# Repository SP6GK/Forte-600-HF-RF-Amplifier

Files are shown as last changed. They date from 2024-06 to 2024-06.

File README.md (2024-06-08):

# Forte 600

This is a hardware repository for a 600 W linear RF amplifier working in the 1.8-30 MHz spectrum. I have performed extensive measurements of the output for different configurations of the output transmission line transformers (TLTs). Unfortunately, I don't have the equipment to test this amplifier above 30 MHz, but according to S11 measurements of the output, it should also cover the 6 m band with lower output power.

I recommend using a single 17 Ohm coaxial cable (HF141-17-FEP by Qaxial) for winding the TLTs. However, as shown in my tests, you can use a parallel combination of 50 and 25 Ohm cables, which are easier to find and less expensive. Such an improvised transformer will have worse Power Added Efficiency (PAE) and won't maintain peak power over the maximum wide bandwidth. The ferrite cores used are Fair-Rite 2661102002.

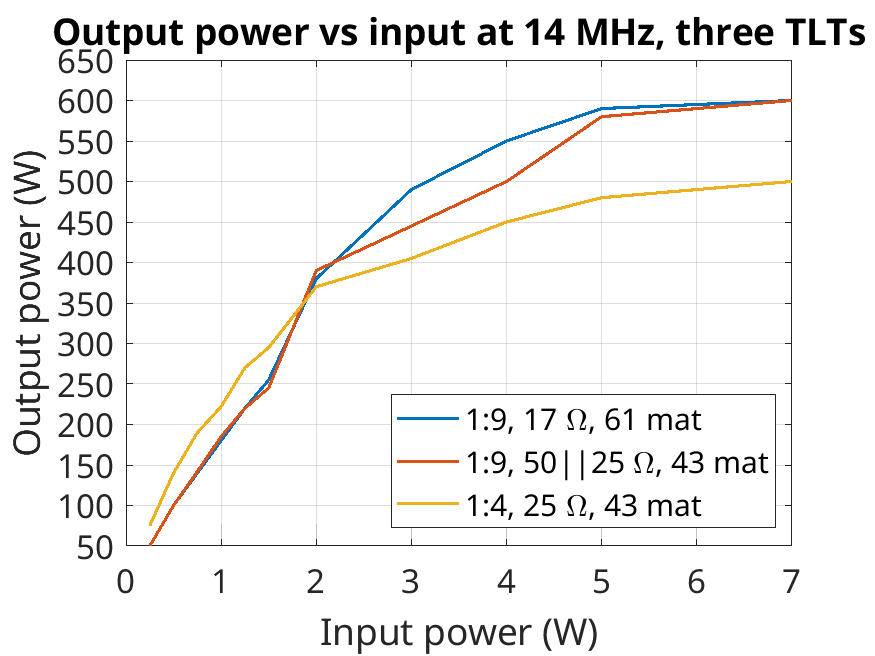
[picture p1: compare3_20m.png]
Output power

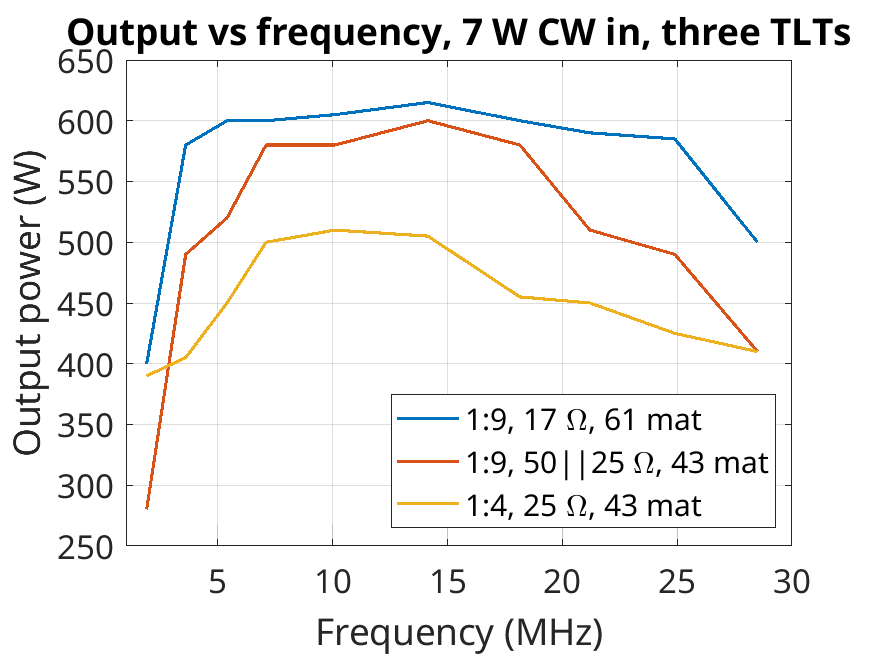
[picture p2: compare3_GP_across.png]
Output power across bands


For more details, you can read my paper or full master thesis, which will be published on my webpage in the coming months: [https://www.sp6gk.com/](https://www.sp6gk.com/).

This project was inspired by Razvan Fatu's 600 W amplifier: [A 600W Broadband HF Amplifier Using Affordable LDMOS Devices](https://qrpblog.com/2019/10/a-600w-broadband-hf-amplifier-using-affordable-ldmos-devices/). The goal of this work was to perform measurements of return loss of the input and output matching network, characterize the linearity, power added efficiency (PAE), and most importantly, the impact of "improvised" TLTs over a "textbook" TLT.

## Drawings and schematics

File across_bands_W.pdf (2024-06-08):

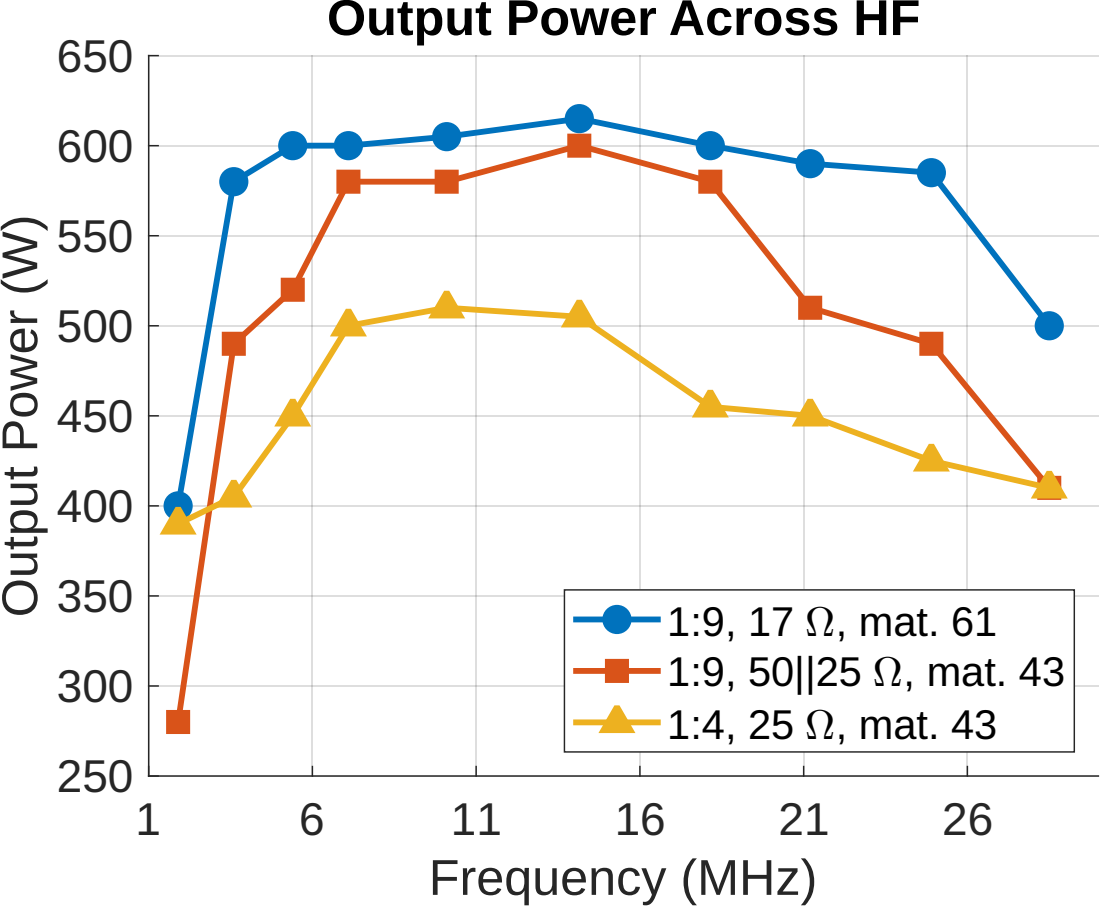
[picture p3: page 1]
Frequency (MHz); utp; 1:9, 17 +, mat. 61 1:9, 50||25 +, mat. 43 1:4, 25 +, mat. 43

Output Power Across HF

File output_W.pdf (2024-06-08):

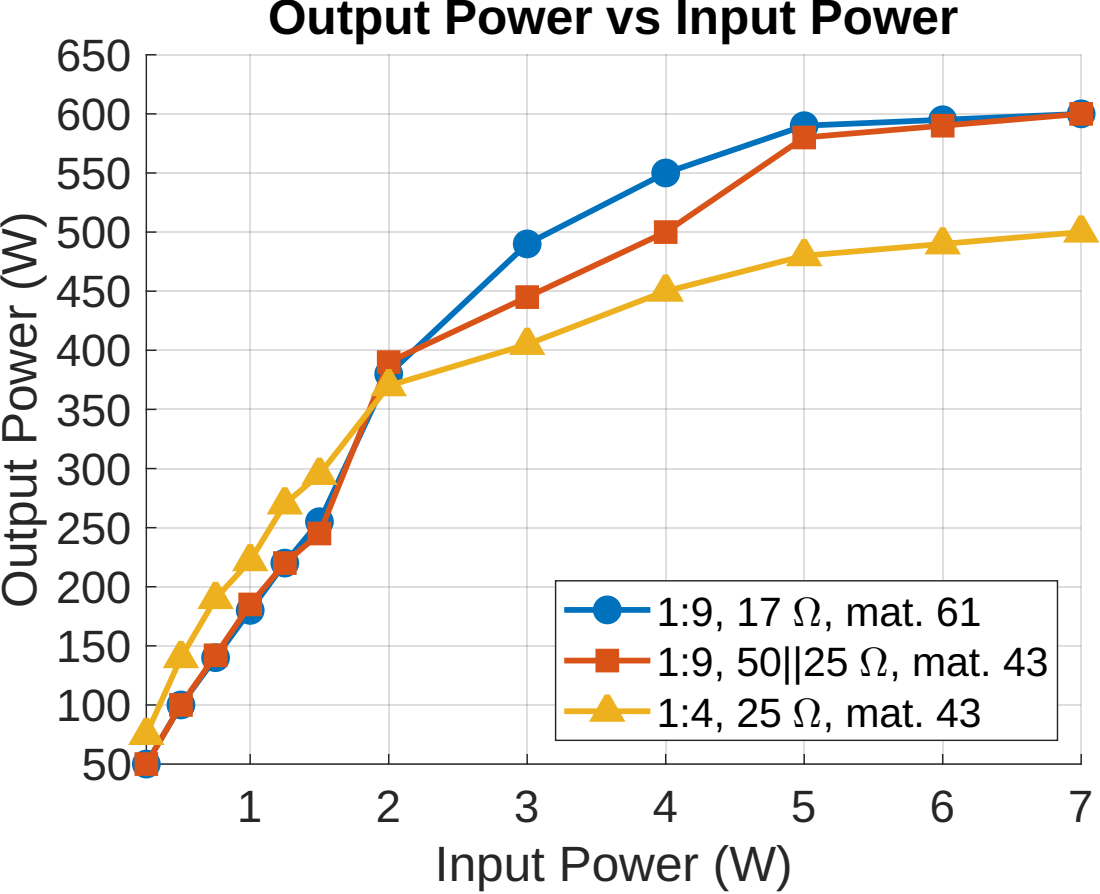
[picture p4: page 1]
7 Input Power (W); Output Power (W)

1:9, 1 | 7 +, m | a t. 6 | 1
1:9, 5 | 0||2 | 5 +, m | a t. 4 3
1:4, 2 | 5 +, m | a t. 4 | 3

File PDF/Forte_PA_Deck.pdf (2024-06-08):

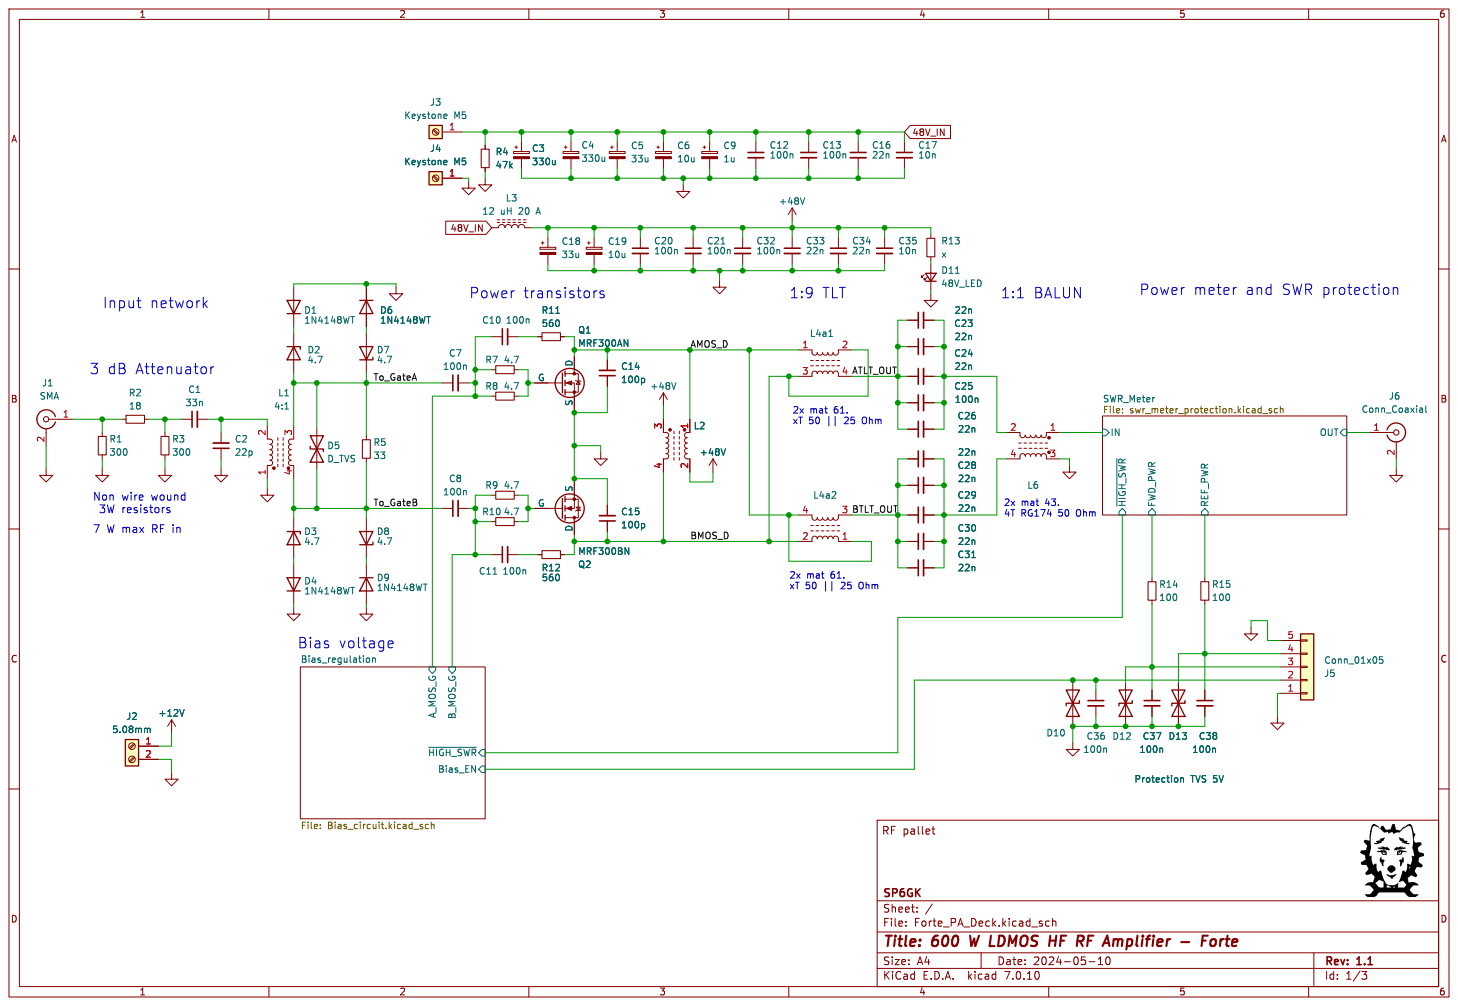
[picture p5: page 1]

Input network Non wire wound

2x mat 43. 4T RG174 50 Ohm 3 dB Attenuator

3W resistors 7 W max RF in

Id: 1/3 Title: 600 W LDMOS HF RF Amplifier - Forte

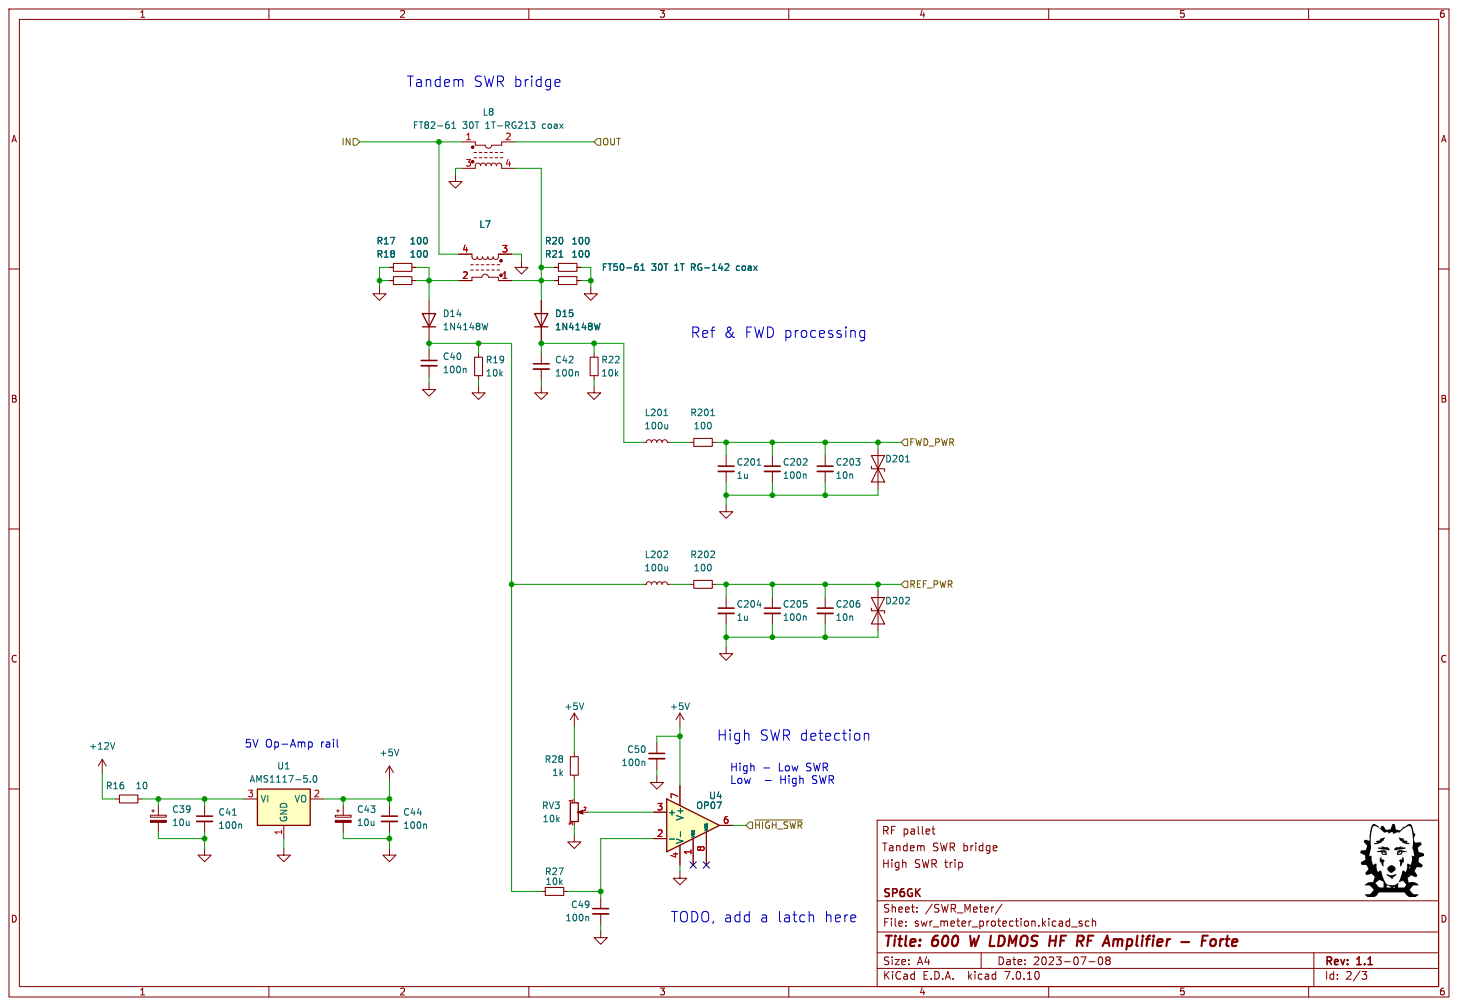
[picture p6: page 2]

Tandem SWR bridge
Low - High SWR Ref & FWD processing

Id: 2/3 Title: 600 W LDMOS HF RF Amplifier - Forte

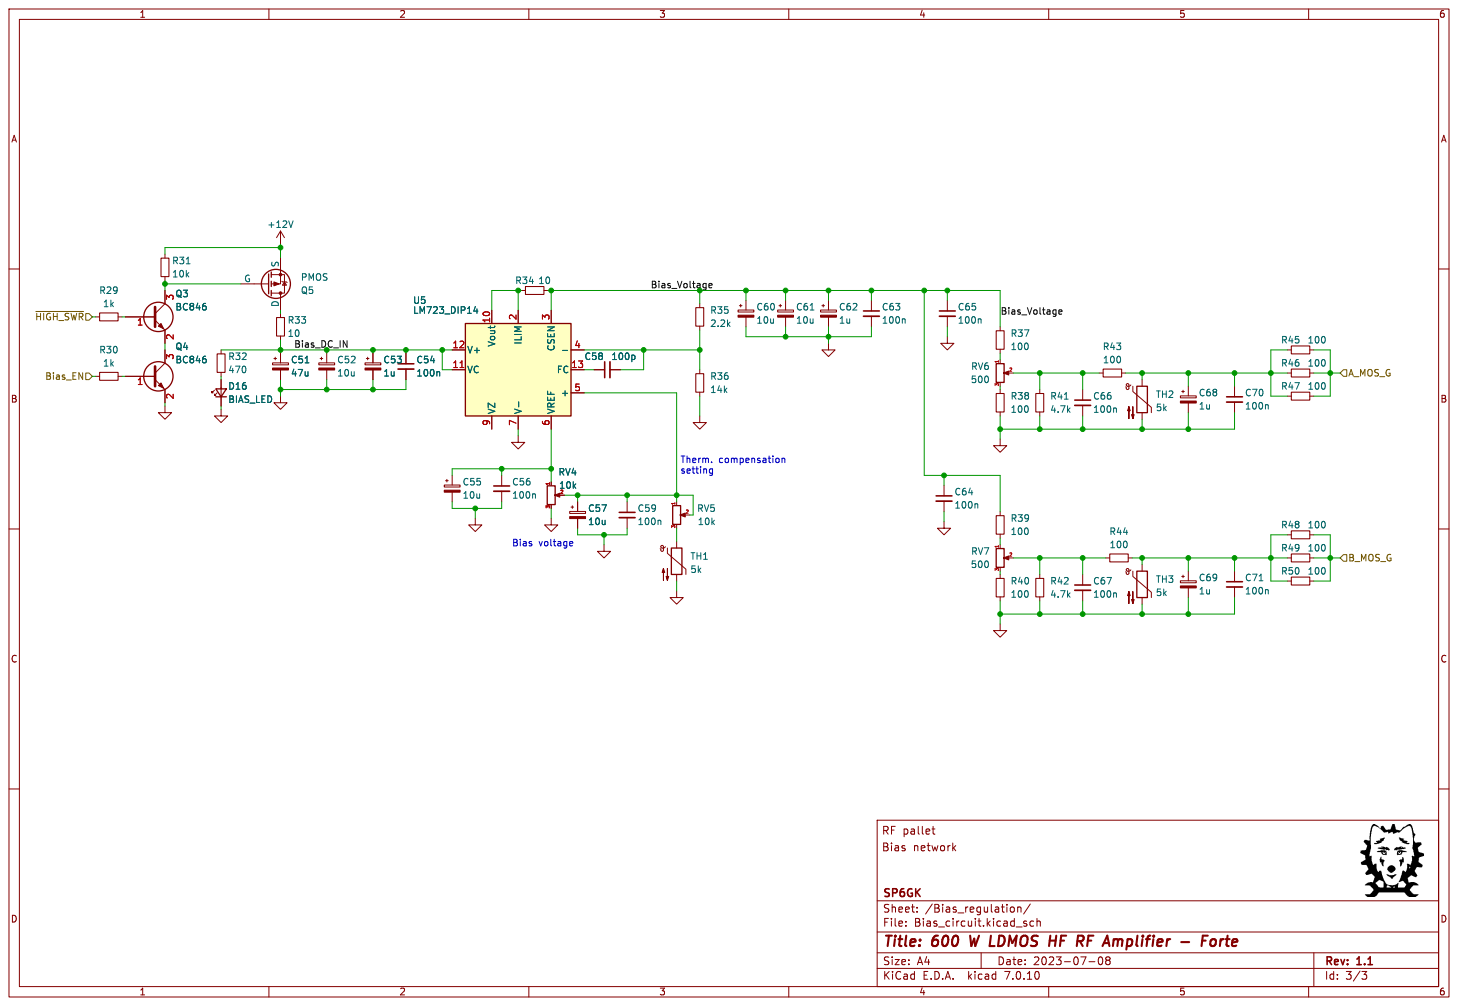
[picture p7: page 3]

Id: 3/3 Title: 600 W LDMOS HF RF Amplifier - Forte

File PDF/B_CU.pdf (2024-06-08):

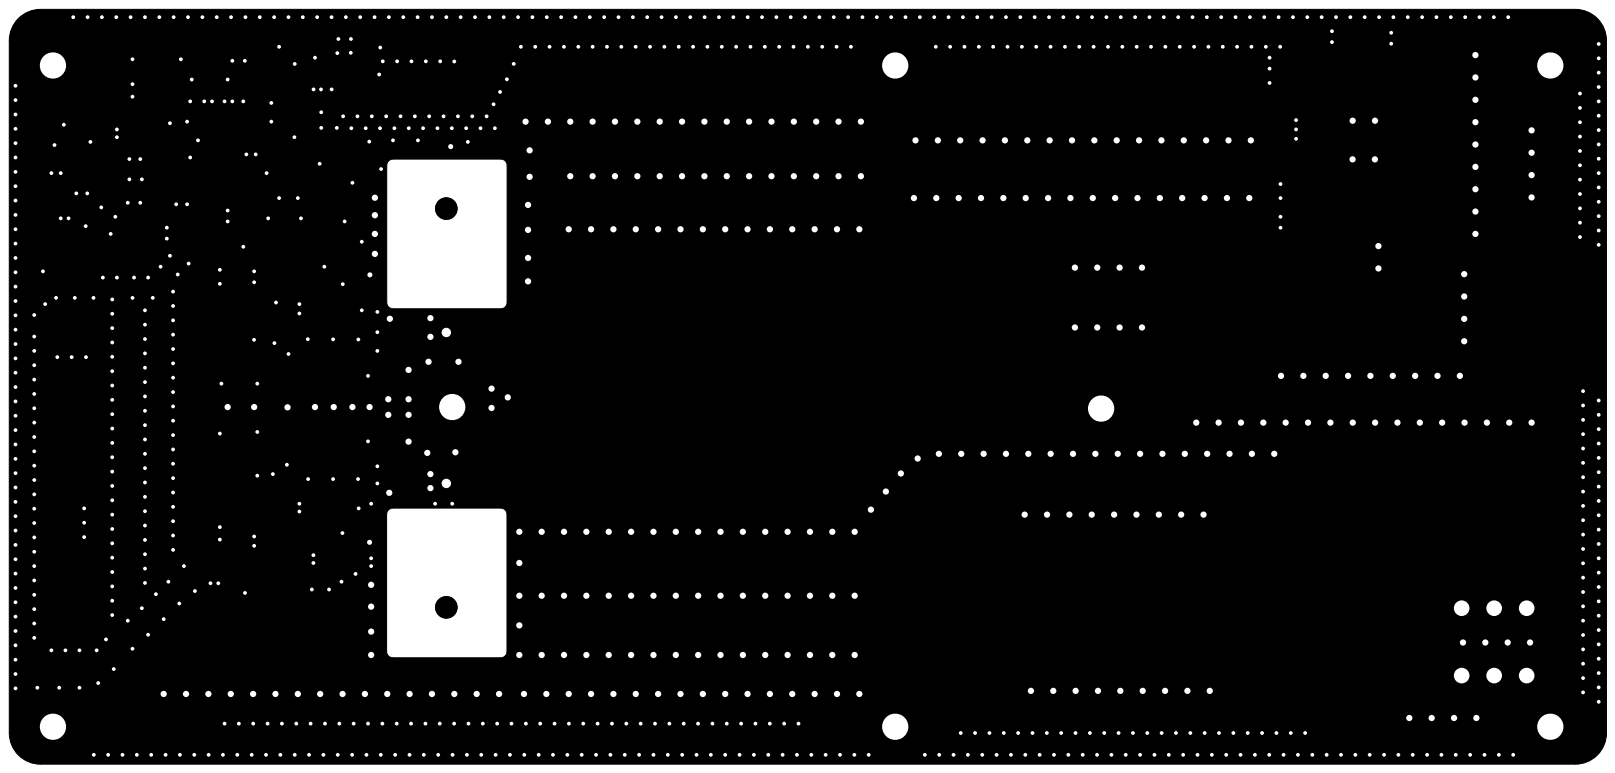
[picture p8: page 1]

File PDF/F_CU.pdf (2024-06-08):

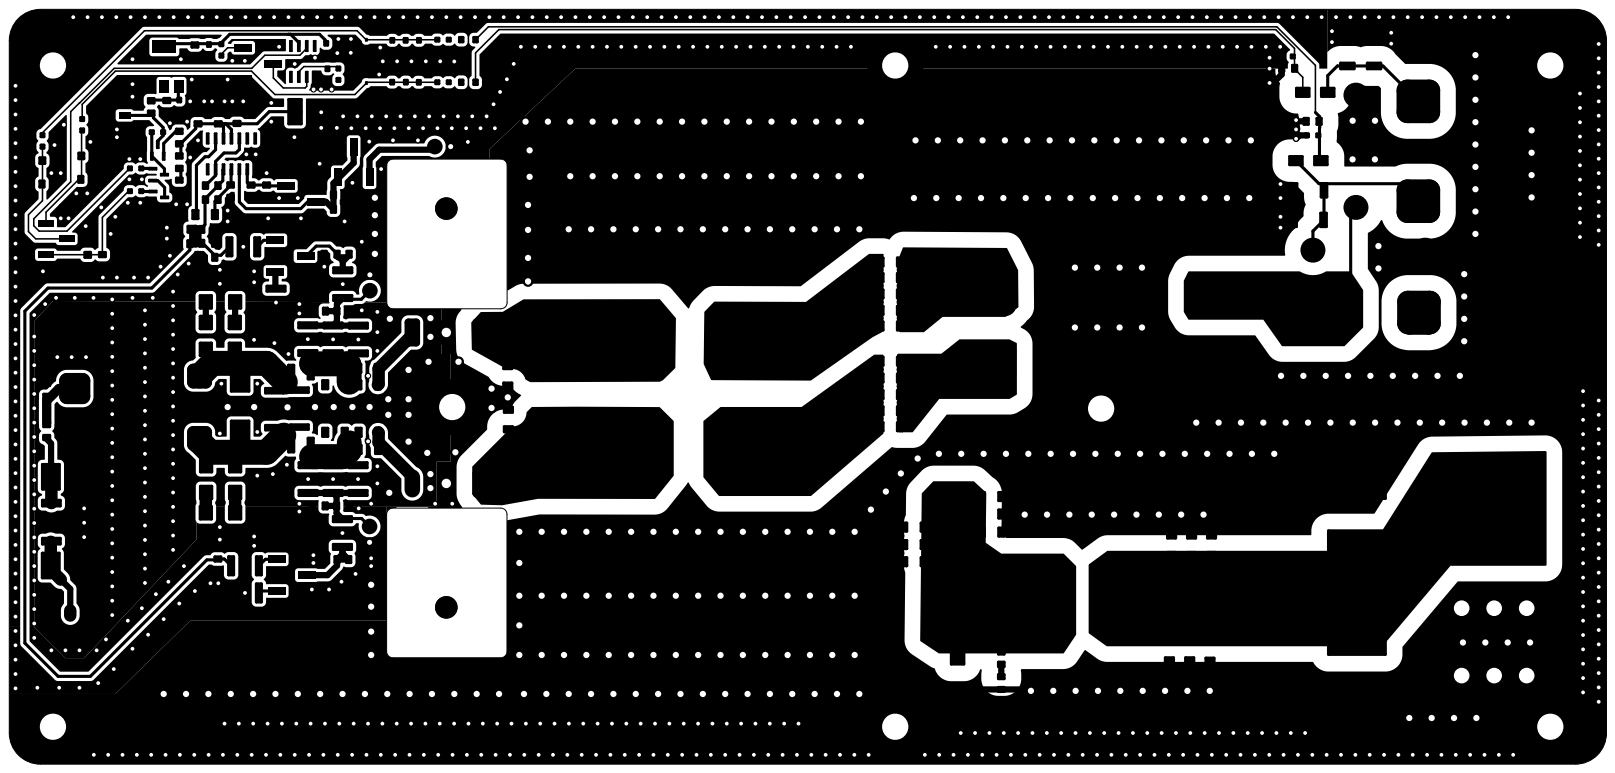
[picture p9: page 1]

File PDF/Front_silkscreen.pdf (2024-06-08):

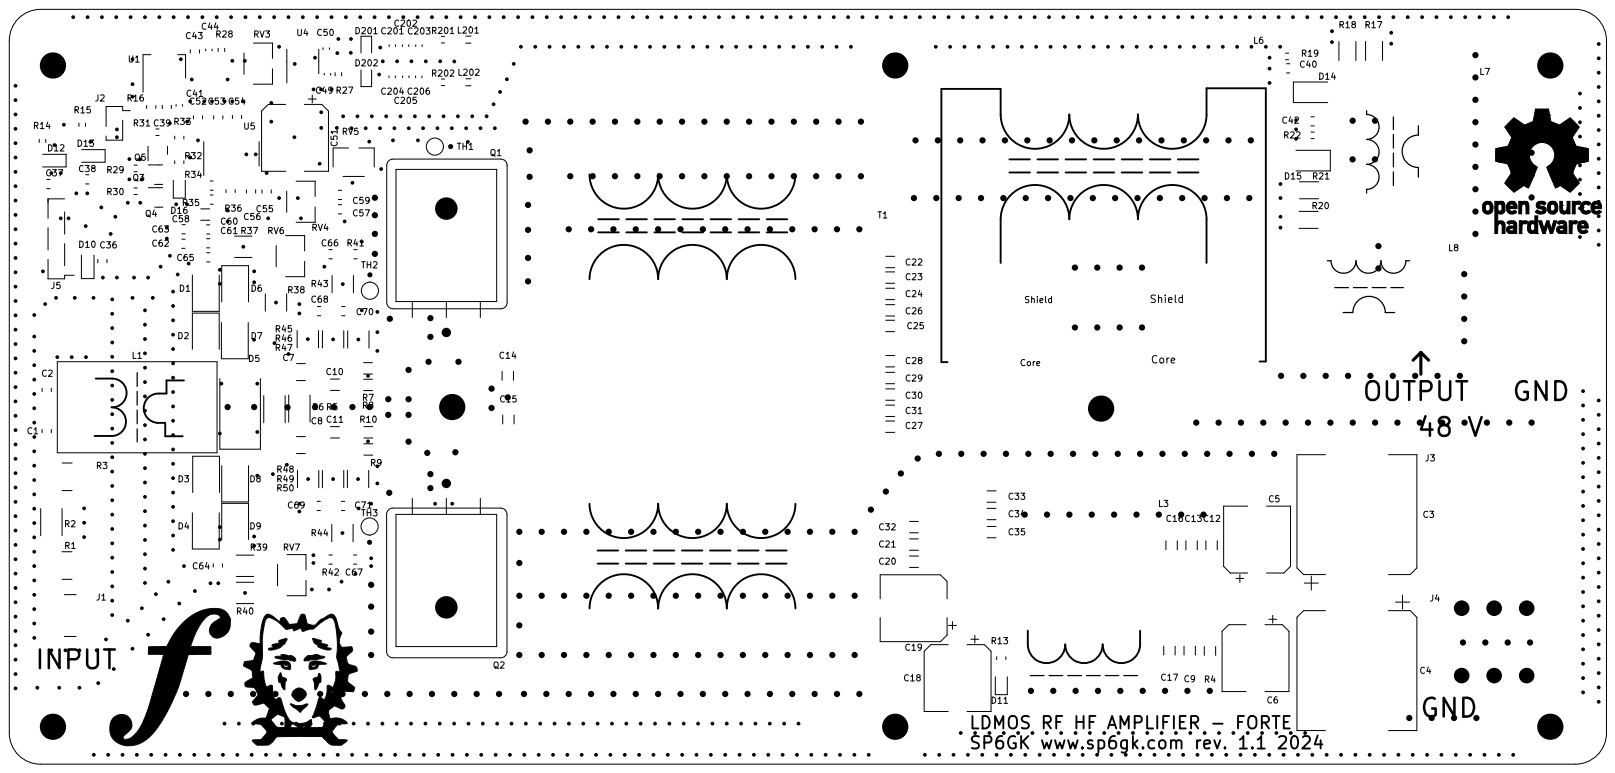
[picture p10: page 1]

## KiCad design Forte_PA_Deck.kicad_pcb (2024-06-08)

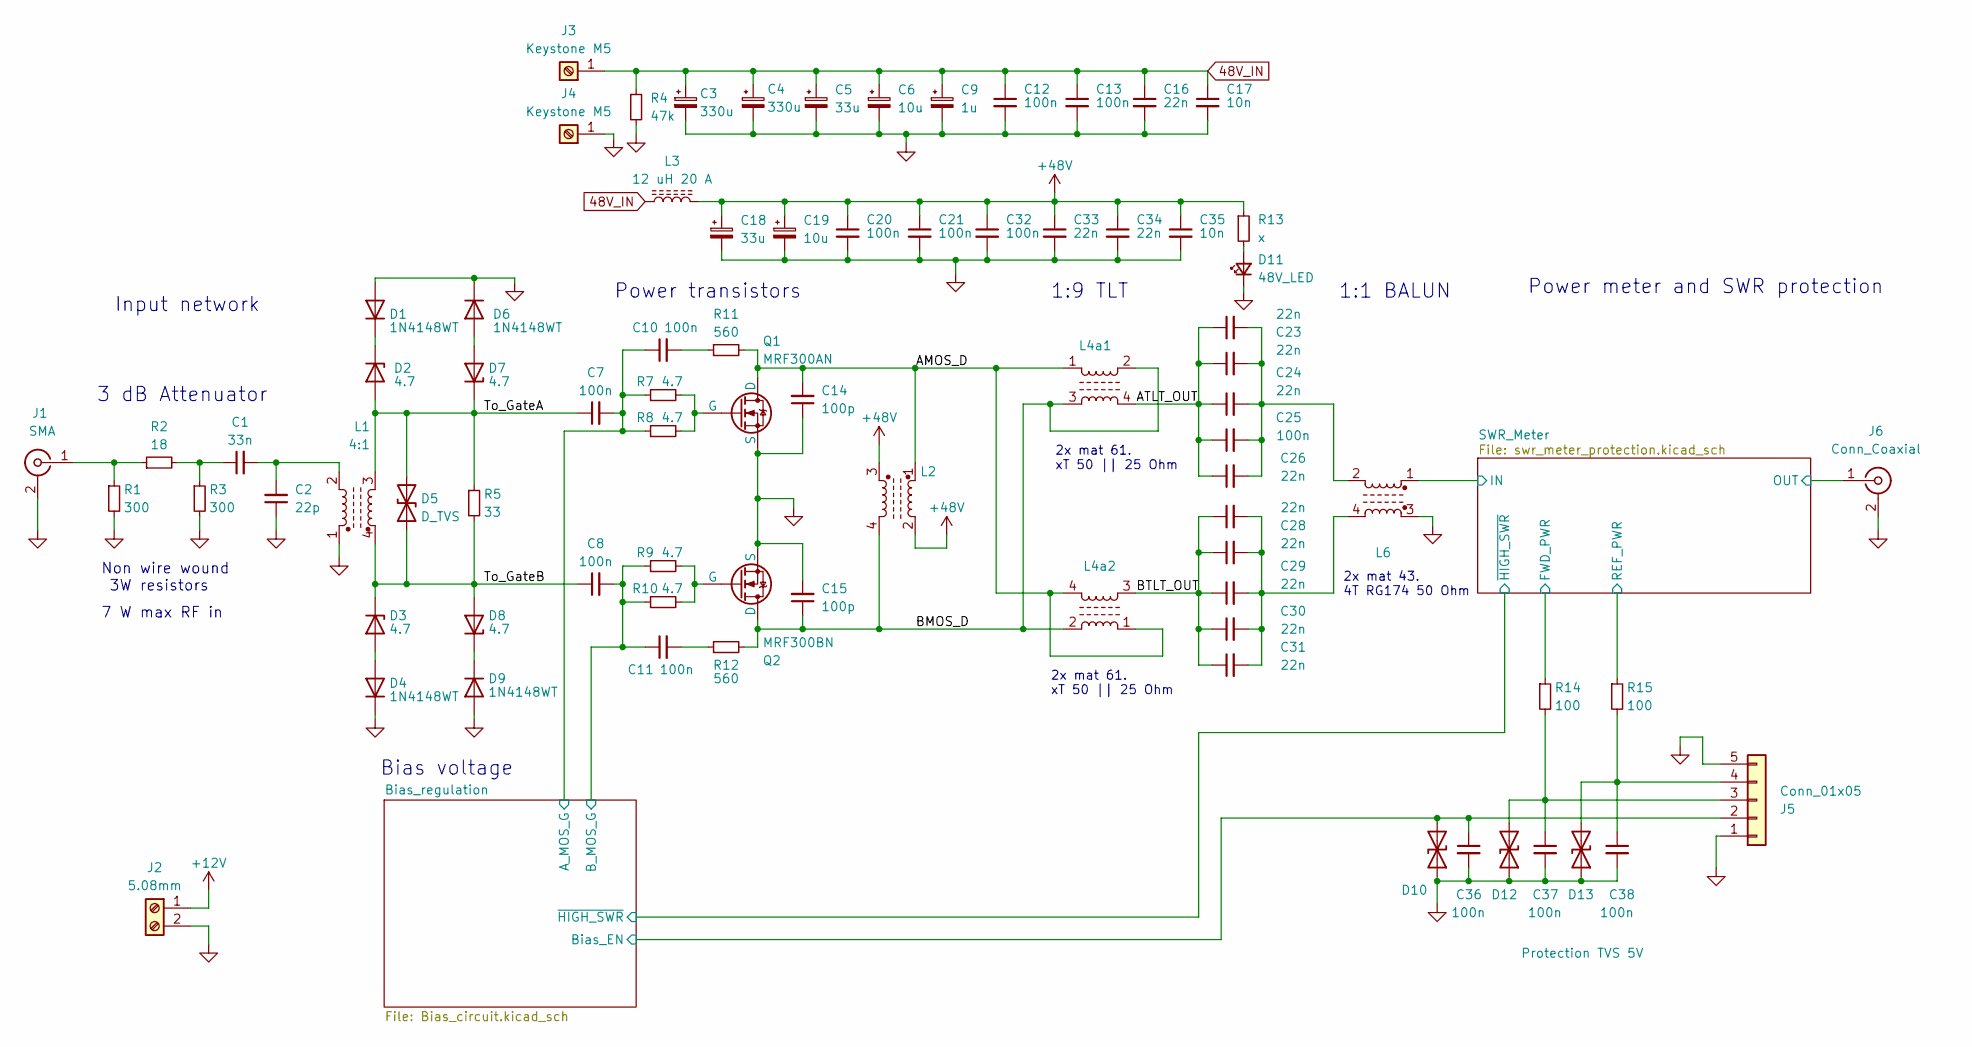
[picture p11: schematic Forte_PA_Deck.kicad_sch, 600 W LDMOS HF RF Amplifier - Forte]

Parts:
C1: 33n; C_0805_2012Metric_Pad1.18x1.45mm_HandSolder
C2: 22p; C_0805_2012Metric_Pad1.18x1.45mm_HandSolder
C3, C4: 330u; CP_Elec_18x17.5
C5, C18: 33u; CP_Elec_10x10.5
C6, C19: 10u; CP_Elec_10x10.5
C7, C8: 100n; C_1210_3225Metric_Pad1.33x2.70mm_HandSolder
C9: 1u; C_1206_3216Metric_Pad1.33x1.80mm_HandSolder
C10, C11, C12, C13, C20, C21, C25, C32: 100n; C_1206_3216Metric_Pad1.33x1.80mm_HandSolder
C14, C15: 100p; C_1206_3216Metric_Pad1.33x1.80mm_HandSolder
C16, C22, C23, C24, C26, C27, C28, C29, C30, C31, C33, C34: 22n; C_1206_3216Metric_Pad1.33x1.80mm_HandSolder
C17, C35: 10n; C_1206_3216Metric_Pad1.33x1.80mm_HandSolder
C36, C37, C38: 100n; C_0805_2012Metric_Pad1.18x1.45mm_HandSolder
D1, D4, D6, D9: 1N4148WT; D_SMB
D2, D3, D7, D8: 4.7; D_SMB
D5: D_TVS; D_SMC_Handsoldering
D10: 3.6; D_SMF
D11: 48V_LED; LED_0805_2012Metric_Pad1.15x1.40mm_HandSolder
D12, D13: Protection TVS 5V; D_SMF
J1: SMA; SMA_Amphenol_132134-10_Vertical
J2: 5.08mm; PinSocket_1x02_P2.54mm_Vertical_SMD_Pin1Right
J3, J4: Keystone M5; M5_screw_terminal_Keystone
J5: Conn_01x05; PinHeader_1x05_P2.54mm_Vertical_SMD_Pin1Left
J6: Conn_Coaxial; Coax_connector
L1: 4:1; Binocular_trafo_small
L2: L_Ferrite_Coupled; VDD_Pads
L3: 12 uH 20 A; EMI_inductor
L4a1, L4a2: L_Ferrite_Coupled; TLT_Trafo
L6: 2x mat 43. 4T RG174 50 Ohm; Trafo_623-2661102002
Q1: MRF300AN; TO-247-3_Horizontal_TabDown
Q2: MRF300BN; TO-247-3_Horizontal_TabDown
R1, R3: 300; R_2816_7142Metric_Pad3.20x4.45mm_HandSolder
R2: 18; R_2512_6332Metric_Pad1.40x3.35mm_HandSolder
R4: 47k; C_1206_3216Metric_Pad1.33x1.80mm_HandSolder
R5: 33; R_2512_6332Metric
R7, R8, R9, R10: 4.7; C_1206_3216Metric_Pad1.33x1.80mm_HandSolder
R11, R12: 560; R_2512_6332Metric_Pad1.40x3.35mm_HandSolder
R13: x; R_0805_2012Metric_Pad1.20x1.40mm_HandSolder
R14, R15: 100; R_0603_1608Metric_Pad0.98x0.95mm_HandSolder

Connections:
48V_IN: C3.1, C4.1, C5.1, C6.1, C9.1, C12.1, C13.1, C16.1, C17.1, J3.1, L3.1, R4.1
+12V: J2.1; also elsewhere on the board
+48V: C18.1, C19.1, C20.1, C21.1, C32.1, C33.1, C34.1, C35.1, L2.2, L2.3, L3.2, R13.1
/AMOS_D: C14.2, L2.1, L4a1.1, L4a2.1, L4a2.4, Q1.3 (D), R11.2; also elsewhere on the board
/ATLT_OUT: C22.1, C23.1, C24.1, C25.1, C26.1, L4a1.4; also elsewhere on the board
/BMOS_D: C15.1, L2.4, L4a1.2, L4a1.3, L4a2.2, Q2.1 (D), R12.2; also elsewhere on the board
/BTLT_OUT: C27.1, C28.1, C29.1, C30.1, C31.1, L4a2.3; also elsewhere on the board
/Bias_regulation/A_MOS_G: C7.2, C10.1, R7.1, R8.1; also elsewhere on the board
/Bias_regulation/B_MOS_G: C8.2, C11.1, R9.1, R10.1; also elsewhere on the board
/Bias_regulation/Bias_EN: C36.1, D10.2 (A2), J5.2; also elsewhere on the board
/SWR_Meter/FWD_PWR: R14.1; also elsewhere on the board
/SWR_Meter/IN: L6.1; also elsewhere on the board
/SWR_Meter/OUT: J6.1 (In); also elsewhere on the board
/SWR_Meter/REF_PWR: R15.1; also elsewhere on the board
/To_GateA: C7.1, D2.2 (A), D5.2 (A2), D7.1 (K), L1.3, R5.1
/To_GateB: C8.1, D3.1 (K), D5.1 (A1), D8.2 (A), L1.4, R5.2
GND: C2.1, C3.2, C4.2, C5.2, C6.2, C9.2, C12.2, C13.2, C14.1, C15.2, C16.2, C17.2, C18.2, C19.2, C20.2, C21.2, C32.2, C33.2, C34.2, C35.2, C36.2, C37.2, C38.2, D1.2 (A), D4.1 (K), D6.1 (K), D9.2 (A), D10.1 (A1), D11.1 (K), D12.1 (A1), D13.1 (A1), J1.2 (Ext), J2.2, J4.1, J5.1, J5.5, J6.2 (Ext), L1.1, L6.3, Q1.2 (S), Q2.2 (S), R1.2, R3.2, R4.2; also elsewhere on the board
unnamed: C1.1, R2.2, R3.1
unnamed: C1.2, C2.2, L1.2
unnamed: C10.2, R11.1
unnamed: C11.2, R12.1
unnamed: C22.2, C23.2, C24.2, C25.2, C26.2, L6.2
unnamed: C27.2, C28.2, C29.2, C30.2, C31.2, L6.4
unnamed: D1.1 (K), D2.1 (K)
unnamed: D3.2 (A), D4.2 (A)
unnamed: D6.2 (A), D7.2 (A)
unnamed: D8.1 (K), D9.1 (K)
unnamed: D11.2 (A), R13.2
unnamed: C37.1, D12.2 (A2), J5.3, R14.2
unnamed: C38.1, D13.2 (A2), J5.4, R15.2
unnamed: J1.1 (In), R1.1, R2.1
unnamed: Q1.1 (G), R7.2, R8.2
unnamed: Q2.3 (G), R9.2, R10.2

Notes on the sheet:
Input network
1:1 BALUN
2x mat 61. xT 50 || 25 Ohm
7 W max RF in
Power transistors
1:9 TLT
2x mat 43. 4T RG174 50 Ohm
Power meter and SWR protection
Bias voltage
3 dB Attenuator
Non wire wound 3W resistors

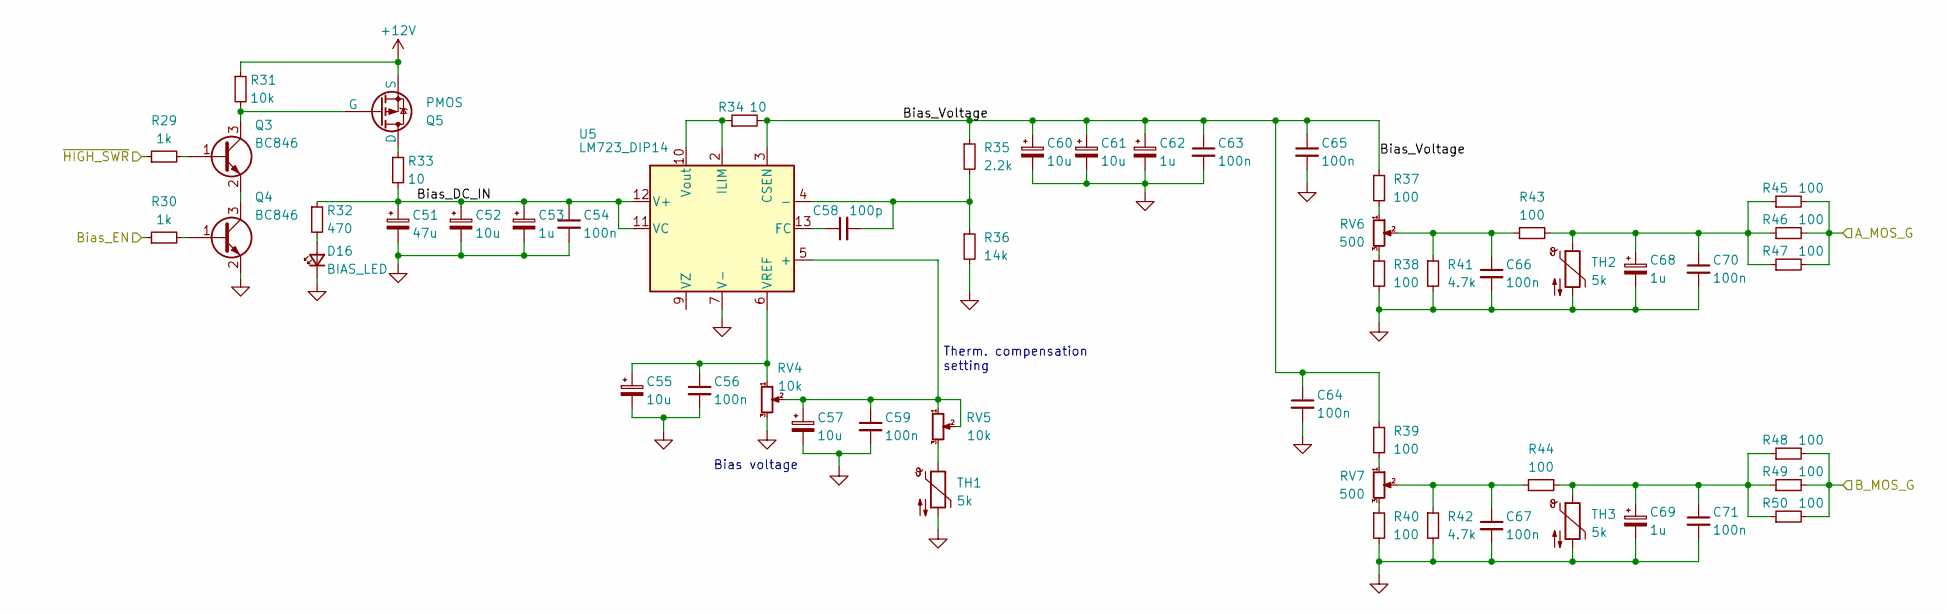
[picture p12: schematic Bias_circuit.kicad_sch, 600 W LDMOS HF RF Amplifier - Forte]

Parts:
C51: 47u; CP_Elec_10x10.5
C52, C55, C57, C60, C61: 10u; C_0805_2012Metric_Pad1.18x1.45mm_HandSolder
C53, C62, C68, C69: 1u; C_0805_2012Metric_Pad1.18x1.45mm_HandSolder
C54, C56, C59, C63, C64, C65, C66, C67, C70, C71: 100n; C_0805_2012Metric_Pad1.18x1.45mm_HandSolder
C58: 100p; C_1206_3216Metric_Pad1.33x1.80mm_HandSolder
D16: BIAS_LED; LED_0805_2012Metric_Pad1.15x1.40mm_HandSolder
Q3, Q4: BC846; SOT-23
Q5: PMOS; SOT-23
R29, R30: 1k; R_0603_1608Metric_Pad0.98x0.95mm_HandSolder
R31: 10k; R_0603_1608Metric_Pad0.98x0.95mm_HandSolder
R32: 470; R_0805_2012Metric_Pad1.20x1.40mm_HandSolder
R33, R34: 10; R_0805_2012Metric_Pad1.20x1.40mm_HandSolder
R35: 2.2k; R_0805_2012Metric_Pad1.20x1.40mm_HandSolder
R36: 14k; R_0805_2012Metric_Pad1.20x1.40mm_HandSolder
R37, R38, R39, R40, R43, R44, R45, R46, R47, R48, R49, R50: 100; R_1812_4532Metric_Pad1.30x3.40mm_HandSolder
R41, R42: 4.7k; C_0805_2012Metric_Pad1.18x1.45mm_HandSolder
RV4, RV5: 10k; Potentiometer_Bourns_3269W_Vertical
RV6, RV7: 500; Potentiometer_Bourns_3269W_Vertical
TH1, TH2, TH3: 5k; R_Axial_DIN0207_L6.3mm_D2.5mm_P2.54mm_Vertical
U5: LM723_DIP14; SO-14_3.9x8.65mm_P1.27mm

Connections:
+12V: Q5.2 (S), R31.1; also elsewhere on the board
/Bias_regulation/A_MOS_G: R45.2, R46.2, R47.2; also elsewhere on the board
/Bias_regulation/B_MOS_G: R48.2, R49.2, R50.2; also elsewhere on the board
/Bias_regulation/Bias_DC_IN: C51.1, C52.1, C53.1, C54.1, R32.1, R33.2, U5.11 (VC), U5.12 (V+)
/Bias_regulation/Bias_EN: R30.1; also elsewhere on the board
/Bias_regulation/Bias_Voltage: C60.1, C61.1, C62.1, C63.1, C64.1, C65.1, R34.2, R35.1, R37.1, R39.1, U5.3 (CSEN)
/Bias_regulation/~HIGH_SWR: R29.1; also elsewhere on the board
GND: C51.2, C52.2, C53.2, C54.2, C55.2, C56.2, C57.2, C59.2, C60.2, C61.2, C62.2, C63.2, C64.2, C65.2, C66.2, C67.2, C68.2, C69.2, C70.2, C71.2, D16.1 (K), Q4.2 (E), R36.2, R38.2, R40.2, R41.2, R42.2, RV4.3, TH1.2, TH2.2, TH3.2, U5.7 (V-); also elsewhere on the board
unnamed: C66.1, R41.1, R43.1, RV6.2
unnamed: C67.1, R42.1, R44.1, RV7.2
unnamed: C68.1, C70.1, R43.2, R45.1, R46.1, R47.1, TH2.1
unnamed: C69.1, C71.1, R44.2, R48.1, R49.1, R50.1, TH3.1
unnamed: D16.2 (A), R32.2
unnamed: Q3.1 (B), R29.2
unnamed: Q3.3 (C), Q5.1 (G), R31.2
unnamed: Q3.2 (E), Q4.3 (C)
unnamed: Q4.1 (B), R30.2
unnamed: Q5.3 (D), R33.1
unnamed: R37.2, RV6.1
unnamed: R38.1, RV6.3
unnamed: R39.2, RV7.1
unnamed: R40.1, RV7.3
unnamed: RV5.3, TH1.1
unnamed: C57.1, C59.1, RV4.2, RV5.1, RV5.2, U5.5 (+)
unnamed: C58.2, R35.2, R36.1, U5.4 (-)
unnamed: C58.1, U5.13 (FC)
unnamed: R34.1, U5.2 (ILIM), U5.10 (Vout)
unnamed: C55.1, C56.1, RV4.1, U5.6 (VREF)

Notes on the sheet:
Bias voltage
Therm. compensation setting

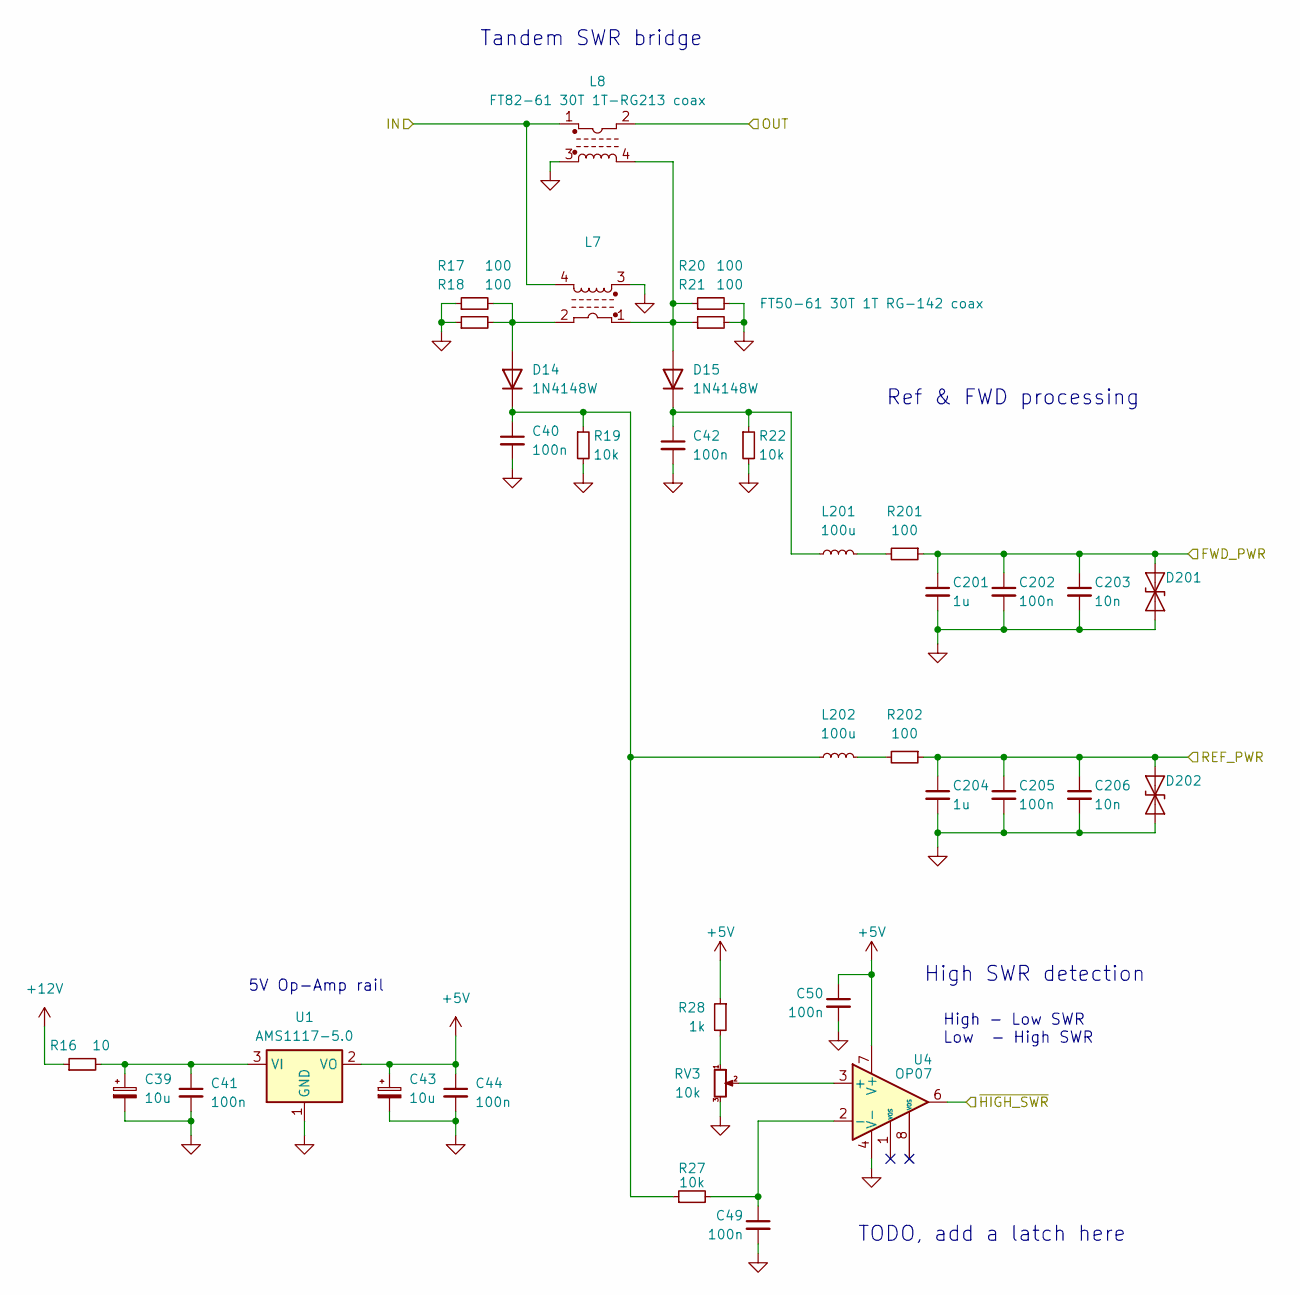
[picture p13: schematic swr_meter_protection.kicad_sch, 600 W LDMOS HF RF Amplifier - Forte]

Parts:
C39, C43: 10u; C_0805_2012Metric_Pad1.18x1.45mm_HandSolder
C40, C42: 100n; C_0805_2012Metric_Pad1.18x1.45mm_HandSolder
C41, C44, C49, C50, C202, C205: 100n; C_0603_1608Metric_Pad1.08x0.95mm_HandSolder
C201, C204: 1u; C_0603_1608Metric_Pad1.08x0.95mm_HandSolder
C203, C206: 10n; C_0603_1608Metric_Pad1.08x0.95mm_HandSolder
D14, D15: 1N4148W; D_SMA
D201, D202: SD12_SOD323; D_SOD-323
L7: FT50-61 30T 1T RG-142 coax; FT82_trafo
L8: FT82-61 30T 1T-RG213 coax; FT82_trafo
L201, L202: 100u; L_0805_2012Metric_Pad1.05x1.20mm_HandSolder
R16: 10; R_0805_2012Metric_Pad1.20x1.40mm_HandSolder
R17, R18, R20, R21: 100; R_2010_5025Metric_Pad1.40x2.65mm_HandSolder
R19, R22, R27: 10k; R_0603_1608Metric_Pad0.98x0.95mm_HandSolder
R28: 1k; R_0603_1608Metric_Pad0.98x0.95mm_HandSolder
R201, R202: 100; R_0603_1608Metric_Pad0.98x0.95mm_HandSolder
RV3: 10k; Potentiometer_Bourns_3269W_Vertical
U1: AMS1117-5.0; SOT-223-3_TabPin2
U4: OP07; SOIC-8_3.9x4.9mm_P1.27mm

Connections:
+5V: C43.1, C44.1, C50.1, R28.1, U1.2 (VO), U4.7 (V+)
+12V: R16.1; also elsewhere on the board
/Bias_regulation/~HIGH_SWR: U4.6; also elsewhere on the board
/SWR_Meter/FWD_PWR: C201.1, C202.1, C203.1, D201.1 (A1), R201.1; also elsewhere on the board
/SWR_Meter/IN: L7.4, L8.1; also elsewhere on the board
/SWR_Meter/OUT: L8.2; also elsewhere on the board
/SWR_Meter/REF_PWR: C204.1, C205.1, C206.1, D202.1 (A1), R202.1; also elsewhere on the board
GND: C39.2, C40.2, C41.2, C42.2, C43.2, C44.2, C49.2, C50.2, C201.2, C202.2, C203.2, C204.2, C205.2, C206.2, D201.2 (A2), D202.2 (A2), L7.3, L8.3, R17.1, R18.1, R19.2, R20.2, R21.2, R22.2, RV3.3, U1.1 (GND), U4.4 (V-); also elsewhere on the board
unnamed: D14.2 (A), L7.2, R17.2, R18.2
unnamed: C40.1, D14.1 (K), L202.1, R19.1, R27.1
unnamed: D15.2 (A), L7.1, L8.4, R20.1, R21.1
unnamed: C42.1, D15.1 (K), L201.1, R22.1
unnamed: L201.2, R201.2
unnamed: L202.2, R202.2
unnamed: R28.2, RV3.1
unnamed: C39.1, C41.1, R16.2, U1.3 (VI)
unnamed: RV3.2, U4.3 (+)
unnamed: C49.1, R27.2, U4.2 (-)

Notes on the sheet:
TODO, add a latch here
Ref & FWD processing
Tandem SWR bridge
High SWR detection
High - Low SWR Low - High SWR
5V Op-Amp rail

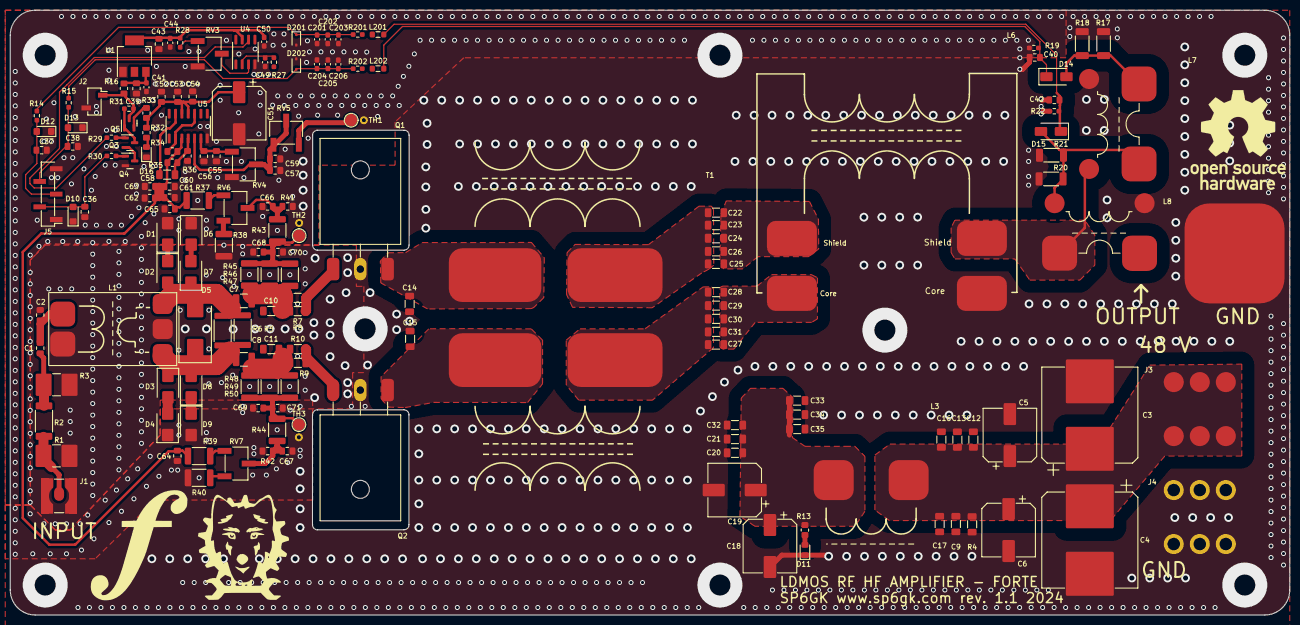
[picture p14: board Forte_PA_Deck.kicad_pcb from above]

Board: 2 copper layers, 256.0 x 121.0 mm, 167 parts (0 on the bottom side), 65 nets.

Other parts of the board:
R6: 33; R_2512_6332Metric
T1: Transformer_1P_1S; TLT_Trafo

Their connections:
/AMOS_D: T1.1 (AA); also elsewhere on the board
/ATLT_OUT: T1.2; also elsewhere on the board
/BMOS_D: T1.3; also elsewhere on the board
/BTLT_OUT: T1.4; also elsewhere on the board
